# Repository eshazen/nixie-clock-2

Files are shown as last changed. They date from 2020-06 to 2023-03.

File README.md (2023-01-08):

# nixie-clock-2
Simple nixie clock based on ATMega861 microcontroller

<table>
  <tr>
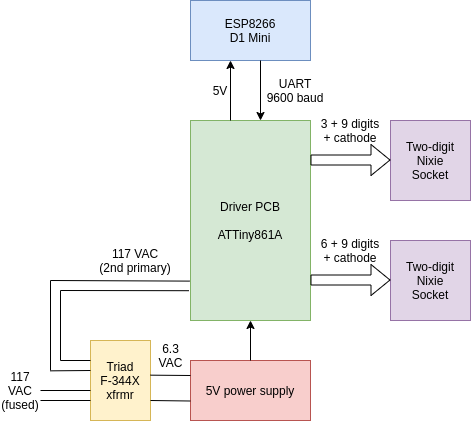
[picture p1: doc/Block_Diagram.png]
    <td width=50%>
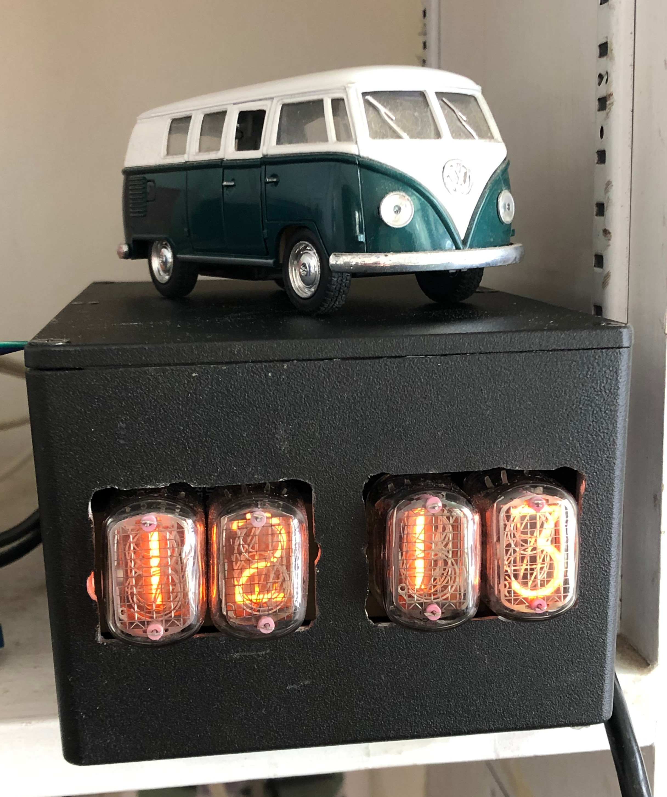
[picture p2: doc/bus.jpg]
    <td>
</table>

```hardware/DriverBoard```

ExpressPCB layout for MCU/Driver board with ATTiny861A driving 4 IN-2B nixies.

```hardware/nixie_socket```

KiCAD design for a two-digit nixie mounting/breakout board

```software/clock```

C code for ATTiny861A to drive the clock display

```software/ESP8266```

Very simple NTP client to get the time via WiFi and send to the ATTiny

## Plans

Thinking of building one for the Kitchen.  Instead of ESP8622, thinking
of one of many DS3231 I2C RTC modules.  This could use the header wires
now used for the ESP.

For power, Triad FD4-10 has a dual 115V primary and 10VCT secondary.
Use a full-wave rectifier or bridge plus 7805 for 5V and the second primary
to generate the HV.  Also need a fuse/holder.

## Notes

On power-up/reboot, the ESP module transmits a blast of serial stuff
at a high bit rate.  This crashes the AVR code.  There's a 30 sec
timer which runs before enabling serial, but apparently the power-up
reset of the ESP sometimes fails.  So for now a reliable
power-up procedure:

* Apply AC power
* Press the reset button on the ESP fairly promptly

Then after 30s timeout things should come up OK.  I'd try to fix
this but can't easily locate my programming adapter for the AVR.

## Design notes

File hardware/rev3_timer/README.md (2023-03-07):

# Rev 3 Timer

This is another try at the "Nixie kitchen timer" originally conceived
in about 2000.  The first rev PCB (ExpressPCB mini board) I used for a
clock in my office; the 2nd rev for another clock with a separate
display board (elsewhere in this repo).

Now planning a new, integrated board with 4 IN-12A/B Nixies, ATMega
328 (168, 88) and the following UI features:

* 4 digit nixie display for primary timer (00:00 to 59:59)
* Multiple simultaneous timers with distinctive sounds
* Water/splash proof case with waterproof buttons

Optional features

* RTC for time display
* Auxiliary LCD display 

## Status

**2023-03-07**

Combo PCB layout done which can be sheared in the middle into control
and display sections.  RTC and aux LCD not included.  Note that we
have a working RTC on the scope clock board so that could be added.

Looking at 3D builds.  See 3D directory.

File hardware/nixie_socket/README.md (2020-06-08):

This is a design for a simple nixie breakout board for two IN-2B or
B-5991 nixies.  I used DB-25 type female pins as individual sockets
for the nixies.

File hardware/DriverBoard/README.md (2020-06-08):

This directory has the ExpressPCB classic design files for a
four-digit nixie clock driver board.  Power is provided by two
inputs... 120V ac through an *isolation transformer* and 5V from any
convenient supply.  Nixies are driven by SN75461 transistor array
drivers.  Note the 90V zener on the common terminal... this protects
the driver chips in case no digits are illuminated.

The drivers are in turn controlled by a long shift register built of
74LS164 octal serial-to-parallel shift register ICs, driven by 4 GPIOs
on the uC.  

The circuitry consisting of C4, R2 etc was supposed to provide a 60Hz
interrupt to the MCU for timekeeping but it never worked right and I
decided to use NTP time loaded serially from an ESP8266.

J4 is an old-school Atmel 10 pin programming connector.  You'll
probably need to make an adapter (as I did) to program the board with
a modern 6-pin cable.

There's an ambient light sensor which may be used at some point to dim
the nixies at night.

Q1 is a MOSFET which is intended to drive an external alarm buzzer.

J2 has 3 GPIOs, of which I use only pin 3 as a serial input.

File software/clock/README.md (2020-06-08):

Software for Nixie Clock on ExpressPCB board with ATMega861A

Drives four IN-2B nixies attached via ribbon cables to two-digit
breakout boards.  The wiring is a bit crazy and you will probably have
to just work it out yourself.

9600 baud serial I/O working with some effort:

Timer interrupt at 9600Hz using divide-by-1
clock source (8MHz) divided by 800.
(calculated value 833)

Transmit using timer interrupt.

Receive using pin-change to start, set timer
to half-value to reset timer interrupts to occur
in the middle of the bit period.

Time is updated (only) by serial messages received at 9600 baud with
the format "*hhmm$".

Build using Makefile.  Expects avr-libc and avr-gcc, binutils and
avrdude to be installed.

"make flash" to program your board once you set the avrdude options.

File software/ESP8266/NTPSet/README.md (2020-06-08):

ESP8266 NTP client.  Connect to WiFi, obtain time from NTP server once
every 10s and send via 9600 baud UART to the clock as "*hhmm$"

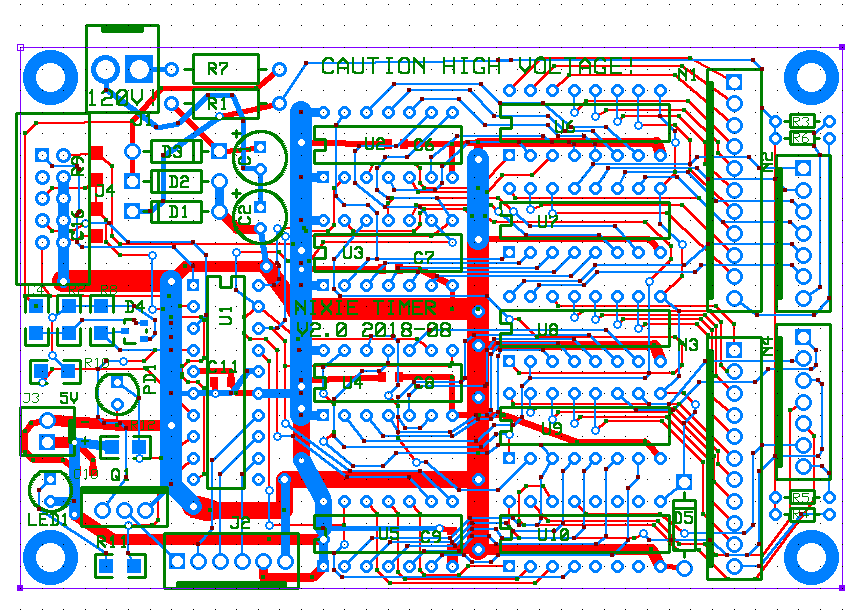
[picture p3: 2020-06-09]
hardware/DriverBoard/layout.png

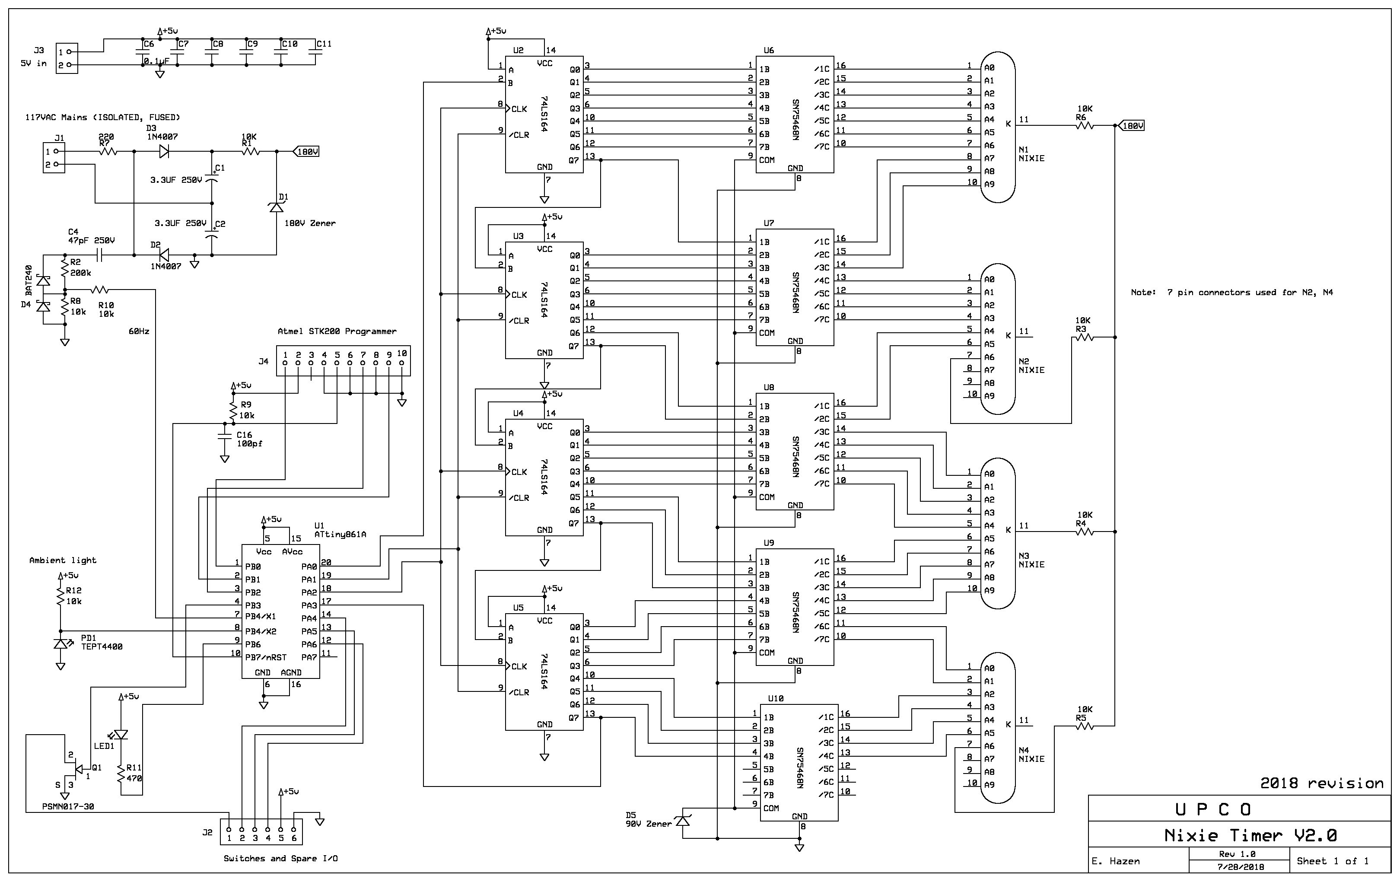
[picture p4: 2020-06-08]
hardware/DriverBoard/timer_sch.png

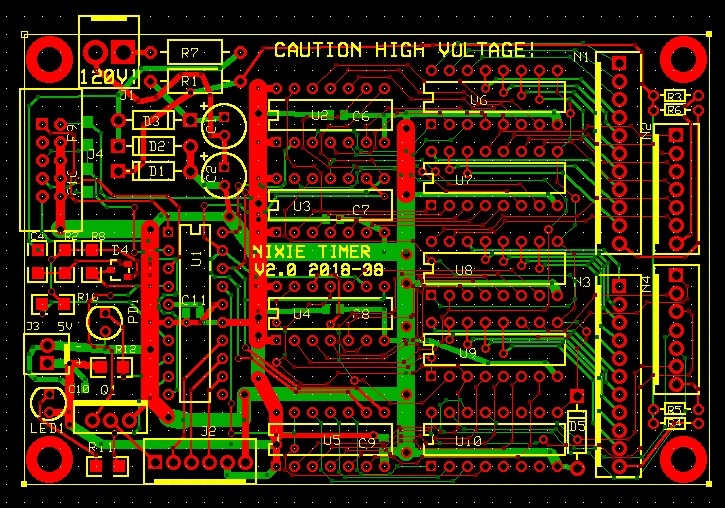
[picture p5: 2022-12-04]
pix/driver_layout.png

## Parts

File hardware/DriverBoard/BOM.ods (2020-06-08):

C1 | 3.3UF 250V | 1189-2223-ND
C2 | 3.3UF 250V | 1189-2223-ND
C4 | 47pF 250V | 311-3219-1-ND
C6 | 0.1uF | 311-1361-1-ND
C7 |  | 311-1361-1-ND
C8 |  | 311-1361-1-ND
C9 |  | 311-1361-1-ND
C10 |  | 311-1361-1-ND
C11 |  | 311-1361-1-ND
C16 | 100pf | 478-3999-1-ND
D1 | 180V Zener | C1Z180BCT-ND
D2 | 1N4007 | 1N4007-TPMSCT-ND
D3 | 1N4007 | 1N4007-TPMSCT-ND
D4 | BAT240 | BAT240AE6327HTSA1CT-ND
D5 | 90V Zener | 1N4763ACT-ND
J1 |  | WM4620
J2 | SIP 6 | S1211EC-06-ND
J3 |  | 732-5315-ND
J4 | Header 2x5 | MHB10K
LED1 |  | 754-1218-ND
N1 | NIXIE 11pin | S1211EC-11-ND
N2 | NIXIE 7pin | S1211EC-07-ND
N3 | NIXIE 11pin | S1211EC-11-ND
N4 | NIXIE 7pin | S1211EC-07-ND
PD1 | TEPT4400 | 751-1057-ND
Q1 | PSMN017-30 | 1727-7130-ND
R1 | 10K | PPC10KW-1CT-ND
R2 | 200k | RMCF1206FT200KCT-ND
R3 | 10K
R4 | 10K
R5 | 10K
R6 | 10K
R7 | 220 | PPC220W-1CT-ND
R8 | 10k | RMCF1206FT10K0CT-ND
R9 | 10k | RMCF1206FT10K0CT-ND
R10 | 10k | RMCF1206FT10K0CT-ND
R11 | 470 | RMCF1206FT470RCT-ND
R12 | 10k | RMCF1206FT10K0CT-ND
U1 | ATtiny861A | ATTINY861A-PU-ND
U2 | 74LS164 | 296-8248-5-ND
U3 | 74LS164 | 296-8248-5-ND
U4 | 74LS164 | 296-8248-5-ND
U5 | 74LS164 | 296-8248-5-ND
U6 | SN75468N | 296-9917-5-ND
U7 | SN75468N | 296-9917-5-ND
U8 | SN75468N | 296-9917-5-ND
U9 | SN75468N | 296-9917-5-ND
U10 | SN75468N | 296-9917-5-ND
U1-SKT | Qu: 1 | ED3020-ND
U2-5-SKT | Qu: 4 | ED3014-ND
U6-10-SKT | Qu: 5 | ED3016-ND
11 pin hsg | Qu: 2 | WM5342-ND
7 pin hsg | Qu: 2 | WM2805-ND
pin | Qu: 50 | WM2510CT-ND

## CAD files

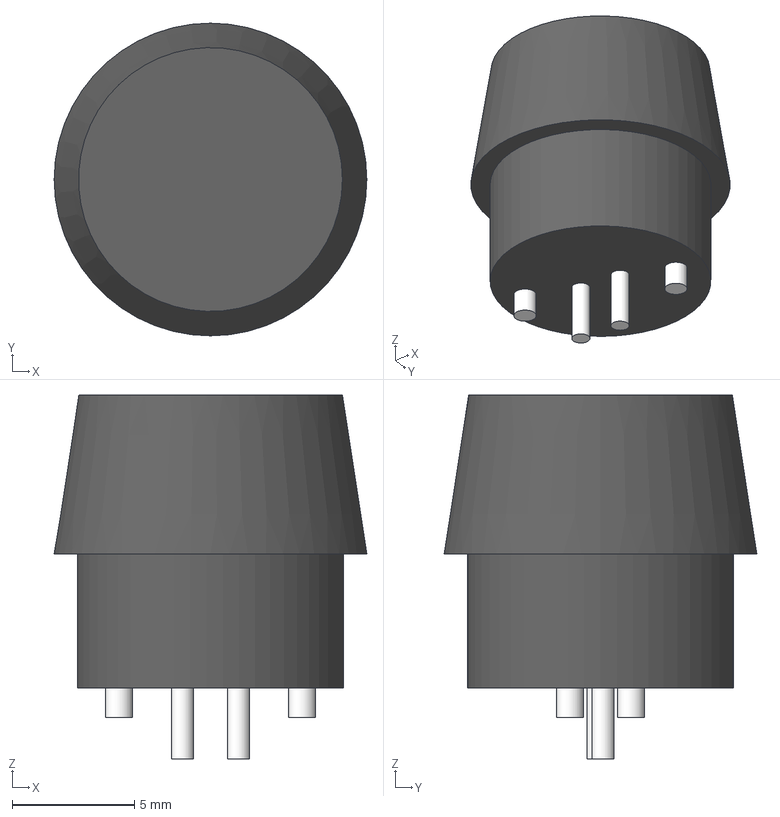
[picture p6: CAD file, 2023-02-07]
3D/rubber-button-Group.step
12.8 x 12.8 x 14.9 mm

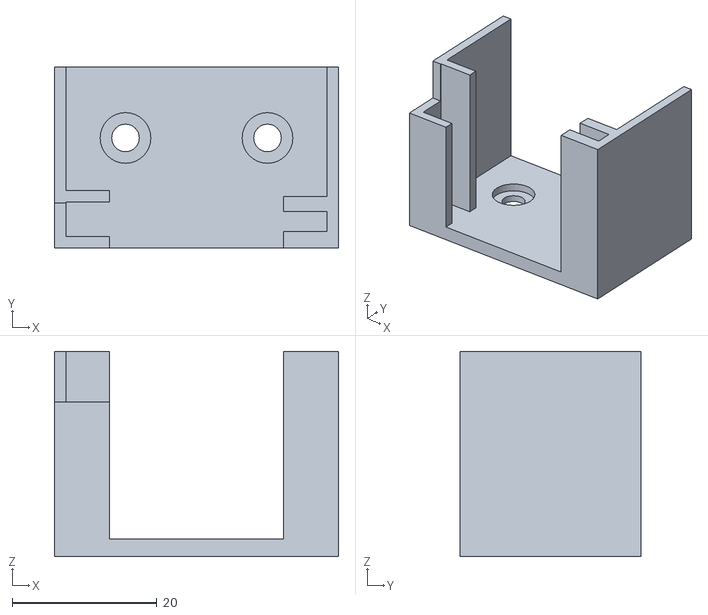
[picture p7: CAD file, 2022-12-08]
box/esp3_holder.stl
39.2 x 25.0 x 28.3

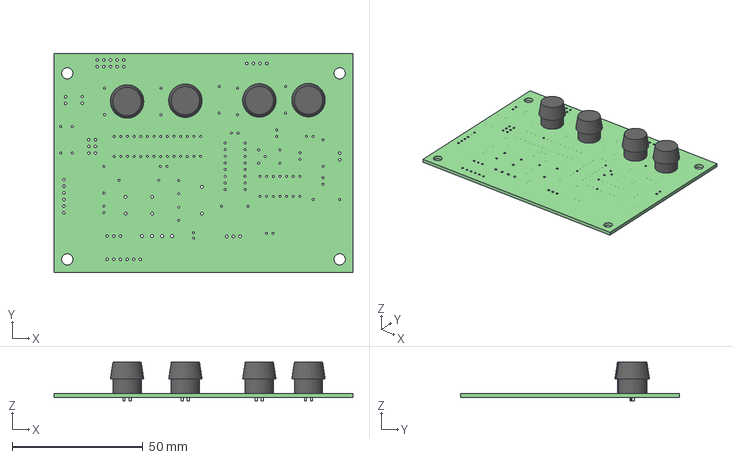
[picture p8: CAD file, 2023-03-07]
hardware/rev3_timer/3D/control.step
114.3 x 83.8 x 14.9 mm
control PCB

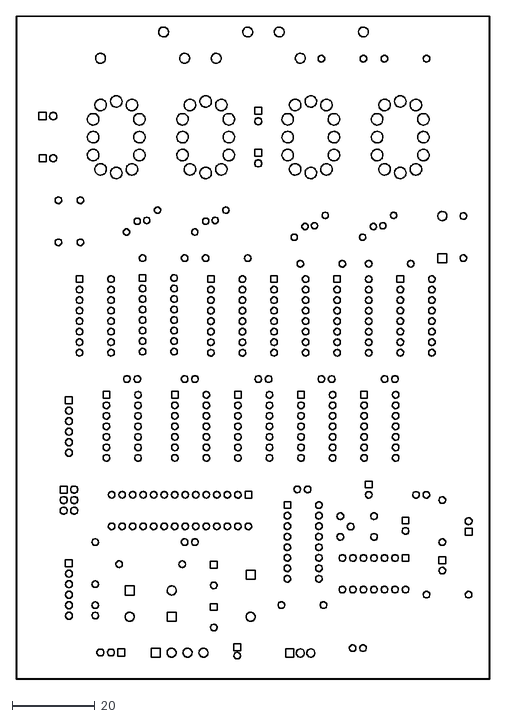
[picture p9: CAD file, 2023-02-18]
hardware/rev3_timer/dxf/rev3_timer-F_Cu.dxf
114.4 x 160.1

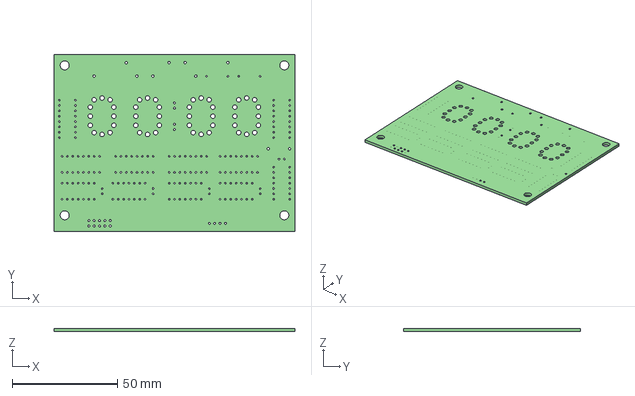
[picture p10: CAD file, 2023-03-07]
hardware/rev3_timer/3D/display.step
114.3 x 83.8 x 1.60 mm

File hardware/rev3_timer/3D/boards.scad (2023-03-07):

//
// test assembly for Nixie timer v3
// "control" and "display" boards hacked from combo board
// > exported as "VRML" from pcbnew
// > converted using imagetostl.com website
//

// two options, "flat" model with sloping control panel
// and "vertical" display model presented side-by-side

module display() {
     translate( [-34.5, 103, 0])
     scale( [1000, 1000, 1000]) import("display.stl");
}

module control() {
     translate( [-34.5, 103+83.4, 0])
     scale( [1000, 1000, 1000]) import("control.stl");
}


translate( [150, 0, 0]) {

// slant controls
color("orange") display();
translate( [0, -45, -5])
rotate([15, 0, 0])
color("green") control();
}

// vertical display
rotate( [90, 0, 0])
color("orange") display();
translate( [0, -70, -27])
rotate( [45, 0, 0])
color("green") control();

// base
translate( [0, -70, -30]) {
     cube( [114.3, 90, 1.6]);
     translate( [0, 90, 0])
     cube( [114.3, 1.6, 120]);
}

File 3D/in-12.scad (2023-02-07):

//
// IN-12 nixie
//

spd = 80;

module pin() {
     cylinder( d=1, h=6);
}

module nixie() {
     % intersection() {
	  cylinder( r=29/2, h=28);
	  translate( [-19.7/2, -30/2, 0])
	       cube( [19.7, 30, 28]);
	  translate( [0, 0, -(spd/2-27)])
	       sphere( d=spd);
     }
     translate( [0, 0, -6]) {
	  for( x=[0:1]) {
	       for( y=[0:2]) {
		    translate( [-11.5/2+x*11.5, -4.5+y*4.5, 0])
			 pin();
	       }
	  }
	  for( x=[0:1]) {
	       for( y=[0:1]) {
		    translate( [-8/2+x*8, -8+y*16, 0])
			 pin();
	       }
	  }
	  translate( [0, -9, 0]) pin();
	  translate( [0, 9, 0]) pin();
     }
}

nixie();

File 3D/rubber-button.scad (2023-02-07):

//
// CK K12C sealed rubber button
//

$fn=64;

module button() {
     color("black") {
	  translate( [0, 0, 5.5])
	       cylinder( r1=6.4, r2=5.4, h=6.5);
	  cylinder( h=5.5, r=10.9/2);
     }
     translate( [-7.5/2, -2.5/2, -1.2])     cylinder( r=1.1/2, h=1.2);
     translate( [7.5/2, 2.5/2, -1.2])    cylinder( r=1.1/2, h=1.2);
     translate( [-2.3/2, -0.1, -2.9])   cylinder( h=2.9, r=0.9/2);
     translate( [2.3/2, 0.1, -2.9])   cylinder( h=2.9, r=0.9/2);
}

button();

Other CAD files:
box/esp_holder.scad

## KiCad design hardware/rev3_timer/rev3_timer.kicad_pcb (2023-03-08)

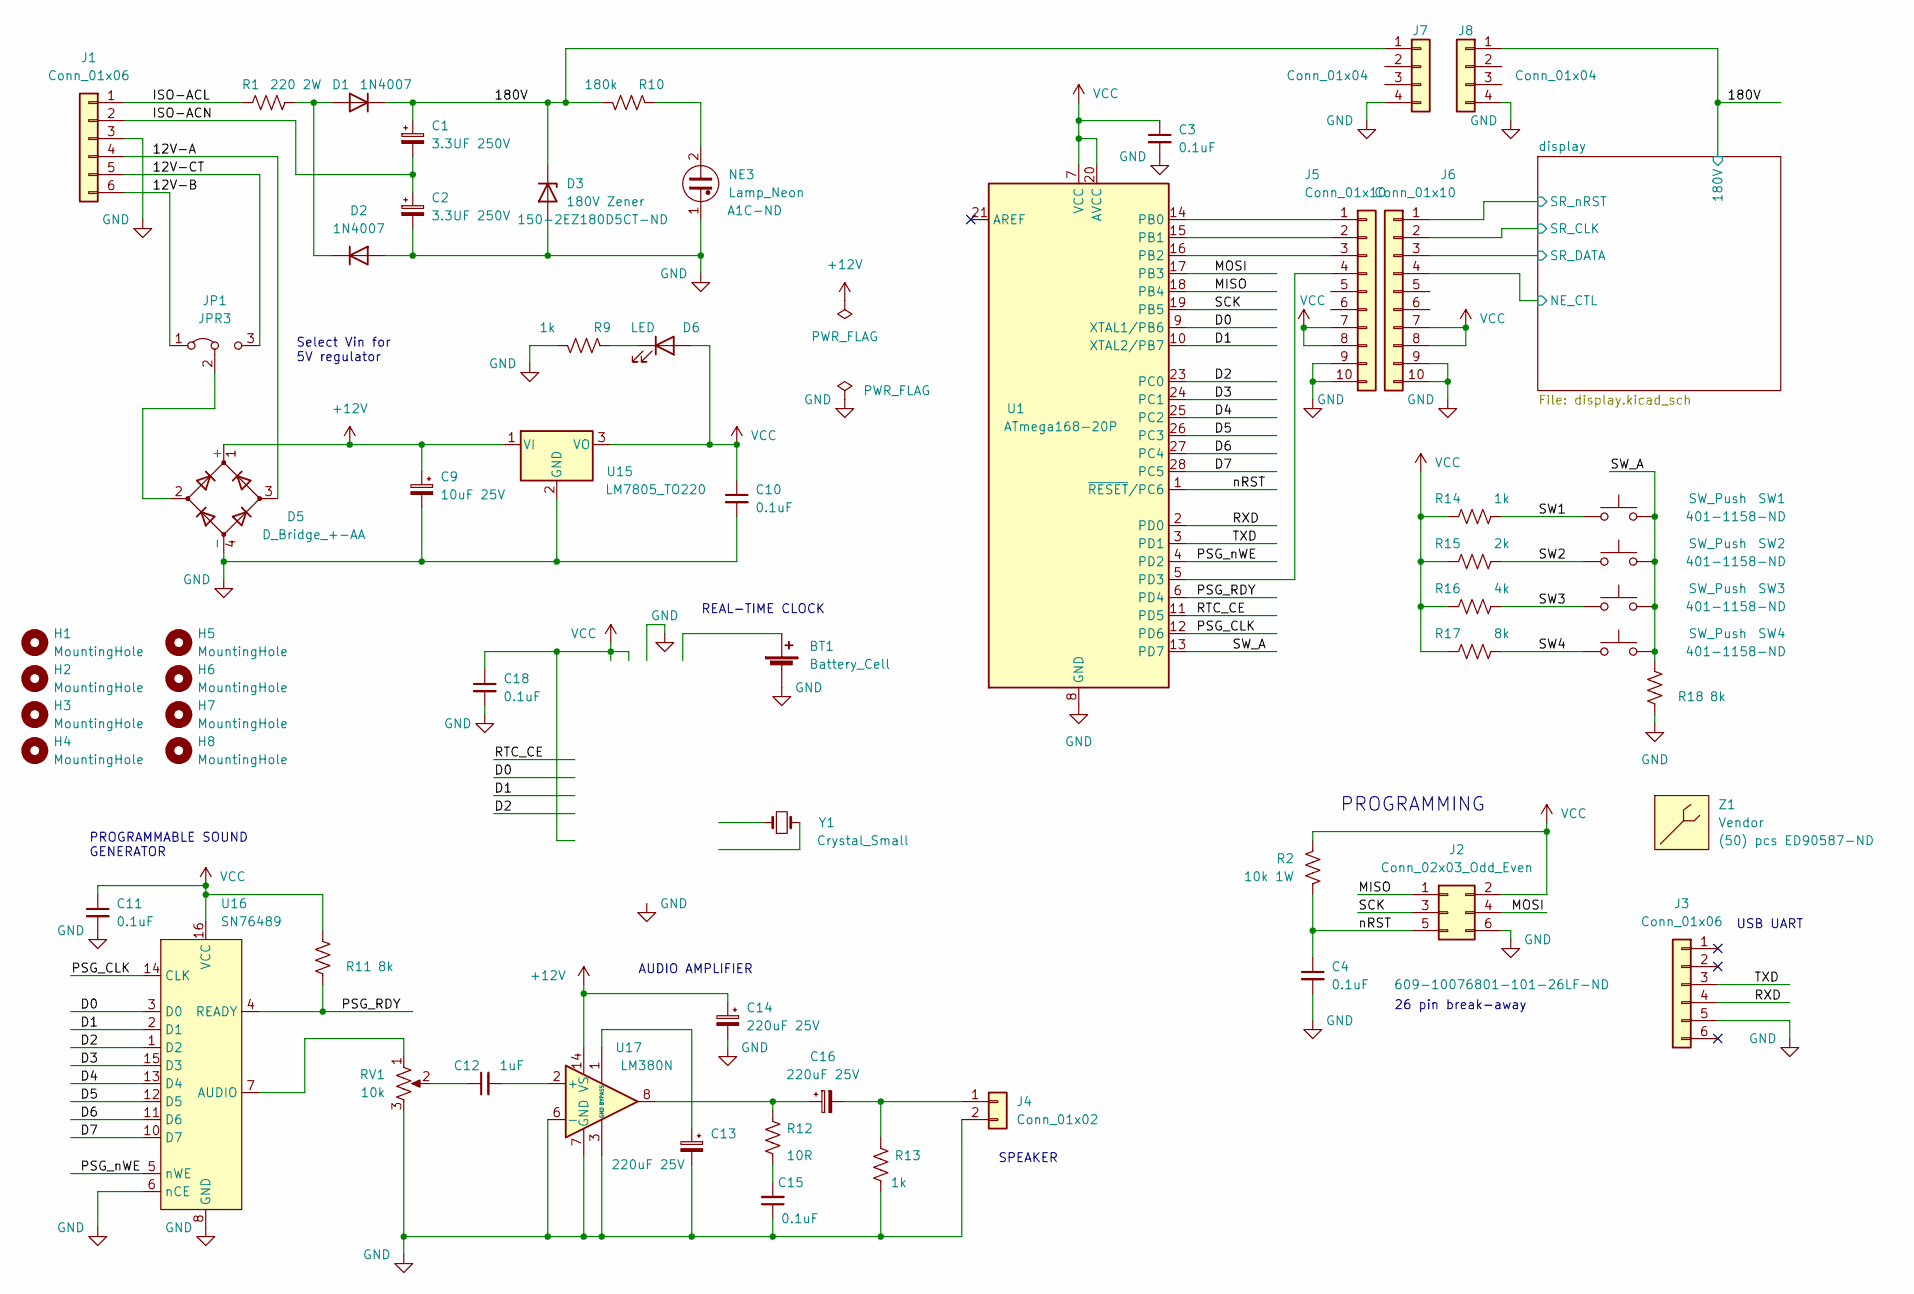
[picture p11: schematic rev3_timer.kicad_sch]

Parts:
BT1: Battery_Cell
C1, C2: 3.3UF 250V; CP_Radial_D8.0mm_P5.00mm
C3, C4, C10, C11, C15, C18: 0.1uF; C_Disc_D3.0mm_W1.6mm_P2.50mm
C9: 10uF 25V; CP_Radial_D5.0mm_P2.00mm
C12: 1uF; C_Rect_L7.2mm_W2.5mm_P5.00mm_FKS2_FKP2_MKS2_MKP2
C13, C14, C16: 220uF 25V; CP_Radial_D6.3mm_P2.50mm
D1, D2: 1N4007; D_DO-41_SOD81_P10.16mm_Horizontal
D3: 180V Zener; D_DO-41_SOD81_P10.16mm_Horizontal
D5: D_Bridge_+-AA; Diode_Bridge_Vishay_KBPM
D6: LED; LED_D3.0mm
H1, H2, H3, H4, H5, H6, H7, H8: MountingHole; MountingHole_4.3mm_M4_Pad
J1, J3: Conn_01x06; PinHeader_1x06_P2.54mm_Vertical
J2: Conn_02x03_Odd_Even; PinHeader_2x03_P2.54mm_Vertical
J4: Conn_01x02; PinHeader_1x02_P2.54mm_Vertical
J5, J6: Conn_01x10; PinHeader_2x05_P2.54mm_Vertical
J7, J8: Conn_01x04; PinHeader_1x04_P2.54mm_Vertical
JP1: JPR3; PinHeader_1x03_P2.54mm_Vertical
NE3: Lamp_Neon; PinHeader_1x02_P2.54mm_Vertical
R1: 220 2W; R_Axial_DIN0309_L9.0mm_D3.2mm_P15.24mm_Horizontal
R2: 10k 1W; R_Axial_DIN0207_L6.3mm_D2.5mm_P10.16mm_Horizontal
R9, R13, R14: 1k; R_Axial_DIN0207_L6.3mm_D2.5mm_P10.16mm_Horizontal
R10: 180k; R_Axial_DIN0207_L6.3mm_D2.5mm_P10.16mm_Horizontal
R11, R17, R18: 8k; R_Axial_DIN0207_L6.3mm_D2.5mm_P10.16mm_Horizontal
R12: 10R; R_Axial_DIN0207_L6.3mm_D2.5mm_P10.16mm_Horizontal
R15: 2k; R_Axial_DIN0207_L6.3mm_D2.5mm_P10.16mm_Horizontal
R16: 4k; R_Axial_DIN0207_L6.3mm_D2.5mm_P10.16mm_Horizontal
RV1: 10k; Potentiometer_ACP_CA6-H2,5_Horizontal
SW1, SW2, SW3, SW4: SW_Push; ck-switch-k12c
U1: ATmega168-20P; DIP-28_W7.62mm
U15: LM7805_TO220; TO-220-3_Vertical
U16: SN76489; DIP-16_W7.62mm_Socket
U17: LM380N; DIP-14_W7.62mm
Y1: Crystal_Small; Crystal_C26-LF_D2.1mm_L6.5mm_Horizontal
Z1: BOM_Item

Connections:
+12V: C9.1, C14.1, D5.1 (+), U15.1 (VI), U17.14 (VS)
/180V: C1.1, D1.1 (K), D3.1 (K), J7.1, J8.1, R10.1; also elsewhere on the board
/D0: U1.9 (XTAL1/PB6), U16.3 (D0); also elsewhere on the board
/D1: U1.10 (XTAL2/PB7), U16.2 (D1); also elsewhere on the board
/D2: U1.23 (PC0), U16.1 (D2); also elsewhere on the board
/D3: U1.24 (PC1), U16.15 (D3)
/D4: U1.25 (PC2), U16.13 (D4)
/D5: U1.26 (PC3), U16.12 (D5)
/D6: U1.27 (PC4), U16.11 (D6)
/D7: U1.28 (PC5), U16.10 (D7)
/ISO-ACL: J1.1, R1.1
/ISO-ACN: C1.2, C2.1, J1.2
/MISO: J2.1, U1.18 (PB4)
/MOSI: J2.4, U1.17 (PB3)
/PSG_CLK: U1.12 (PD6), U16.14 (CLK)
/PSG_RDY: R11.1, U1.6 (PD4), U16.4 (READY)
/PSG_nWE: U1.4 (PD2), U16.5 (nWE)
/RTC_CE: U1.11 (PD5); also elsewhere on the board
/RXD: J3.4, U1.2 (PD0)
/SCK: J2.3, U1.19 (PB5)
/SW1: R14.2, SW1.1
/SW2: R15.2, SW2.1
/SW3: R16.2, SW3.1
/SW4: R17.2, SW4.1
/SW_A: R18.2, SW1.2, SW2.2, SW3.2, SW4.2, U1.13 (PD7)
/TXD: J3.3, U1.3 (PD1)
/display/NE_CTL: J6.4; also elsewhere on the board
/display/SR_CLK: J6.2; also elsewhere on the board
/display/SR_DATA: J6.3; also elsewhere on the board
/display/SR_nRST: J6.1; also elsewhere on the board
/nRST: C4.1, J2.5, R2.1, U1.1 (~RESET/PC6)
unnamed: C12.1, RV1.2
unnamed: C12.2, U17.2 (+)
unnamed: C13.1, U17.1 (BYPASS)
unnamed: C15.2, R12.1
unnamed: C16.1, R12.2, U17.8
unnamed: C16.2, J4.1, R13.2
unnamed: D1.2 (A), D2.1 (K), R1.2
unnamed: D5.2, JP1.2 (C)
unnamed: D6.1 (K), R9.2
unnamed: J5.1, U1.14 (PB0)
unnamed: J5.2, U1.15 (PB1)
unnamed: J5.3, U1.16 (PB2)
unnamed: J5.4, U1.5 (PD3)
unnamed: NE3.2, R10.2
unnamed: RV1.1, U16.7 (AUDIO)
unnamed 135: Y1.1; also elsewhere on the board
unnamed 136: Y1.2; also elsewhere on the board
VCC: C3.1, C10.1, C11.1, C18.1, D6.2 (A), J2.2, J5.7, J5.8, J6.7, J6.8, R2.2, R11.2, R14.1, R15.1, R16.1, R17.1, U1.7 (VCC), U1.20 (AVCC), U15.3 (VO), U16.16 (VCC); also elsewhere on the board

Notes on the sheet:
AUDIO AMPLIFIER
USB UART
Select Vin for 5V regulator
26 pin break-away
PROGRAMMING
PROGRAMMABLE SOUND GENERATOR
REAL-TIME CLOCK
SPEAKER

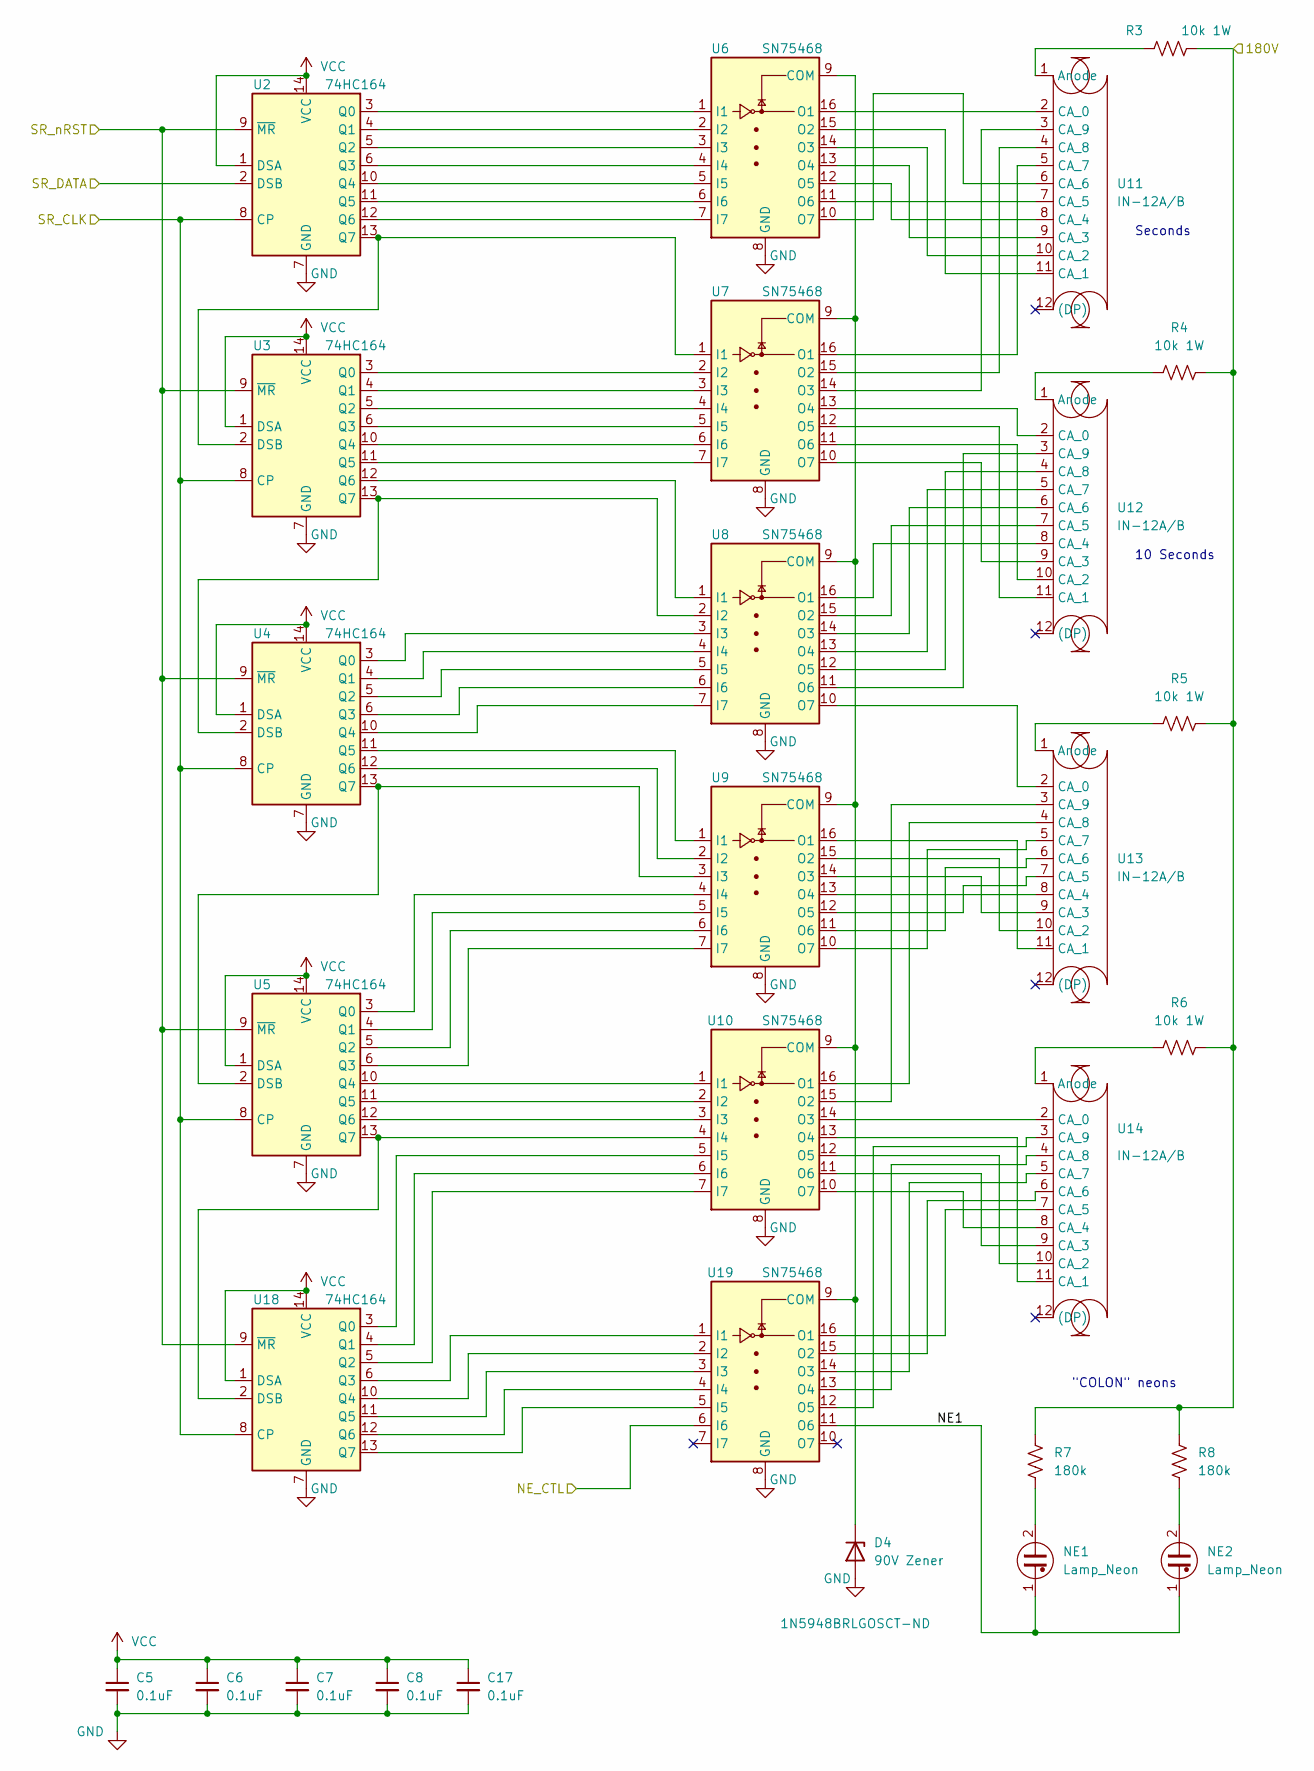
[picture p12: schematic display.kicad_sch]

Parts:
C5, C6, C7, C8, C17: 0.1uF; C_Disc_D3.0mm_W1.6mm_P2.50mm
D4: 90V Zener; D_DO-41_SOD81_P10.16mm_Horizontal
NE1, NE2: Lamp_Neon; PinHeader_1x02_P2.54mm_Vertical
R3, R4, R5, R6: 10k 1W; R_Axial_DIN0414_L11.9mm_D4.5mm_P20.32mm_Horizontal
R7, R8: 180k; R_Axial_DIN0207_L6.3mm_D2.5mm_P10.16mm_Horizontal
U2, U3, U4, U5, U18: 74HC164; DIP-14_W7.62mm_Socket
U6, U7, U8, U9, U10, U19: SN75468; DIP-16_W7.62mm_Socket
U11, U12, U13, U14: IN-12A/B; Nixie-8422-14pin

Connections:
/180V: R3.2, R4.2, R5.2, R6.2, R7.2, R8.2; also elsewhere on the board
/display/NE1: NE1.1, NE2.1, U19.11 (O6)
/display/NE_CTL: U19.6 (I6); also elsewhere on the board
/display/SR_CLK: U2.8 (CP), U3.8 (CP), U4.8 (CP), U5.8 (CP), U18.8 (CP); also elsewhere on the board
/display/SR_DATA: U2.2 (DSB); also elsewhere on the board
/display/SR_nRST: U2.9 (~MR), U3.9 (~MR), U4.9 (~MR), U5.9 (~MR), U18.9 (~MR); also elsewhere on the board
unnamed: D4.1 (K), U6.9 (COM), U7.9 (COM), U8.9 (COM), U9.9 (COM), U10.9 (COM), U19.9 (COM)
unnamed: NE1.2, R7.1
unnamed: NE2.2, R8.1
unnamed: R3.1, U11.1 (Anode)
unnamed: R4.1, U12.1 (Anode)
unnamed: R5.1, U13.1 (Anode)
unnamed: R6.1, U14.1 (Anode)
unnamed: U2.3 (Q0), U6.1 (I1)
unnamed: U2.4 (Q1), U6.2 (I2)
unnamed: U2.5 (Q2), U6.3 (I3)
unnamed: U2.6 (Q3), U6.4 (I4)
unnamed: U2.10 (Q4), U6.5 (I5)
unnamed: U2.11 (Q5), U6.6 (I6)
unnamed: U2.12 (Q6), U6.7 (I7)
unnamed: U2.13 (Q7), U3.2 (DSB), U7.1 (I1)
unnamed: U3.3 (Q0), U7.2 (I2)
unnamed: U3.4 (Q1), U7.3 (I3)
unnamed: U3.5 (Q2), U7.4 (I4)
unnamed: U3.6 (Q3), U7.5 (I5)
unnamed: U3.10 (Q4), U7.6 (I6)
unnamed: U3.11 (Q5), U7.7 (I7)
unnamed: U3.12 (Q6), U8.1 (I1)
unnamed: U3.13 (Q7), U4.2 (DSB), U8.2 (I2)
unnamed: U4.3 (Q0), U8.3 (I3)
unnamed: U4.4 (Q1), U8.4 (I4)
unnamed: U4.5 (Q2), U8.5 (I5)
unnamed: U4.6 (Q3), U8.6 (I6)
unnamed: U4.10 (Q4), U8.7 (I7)
unnamed: U4.11 (Q5), U9.1 (I1)
unnamed: U4.12 (Q6), U9.2 (I2)
unnamed: U4.13 (Q7), U5.2 (DSB), U9.3 (I3)
unnamed: U5.3 (Q0), U9.4 (I4)
unnamed: U5.4 (Q1), U9.5 (I5)
unnamed: U5.5 (Q2), U9.6 (I6)
unnamed: U5.6 (Q3), U9.7 (I7)
unnamed: U5.10 (Q4), U10.1 (I1)
unnamed: U5.11 (Q5), U10.2 (I2)
unnamed: U5.12 (Q6), U10.3 (I3)
unnamed: U5.13 (Q7), U10.4 (I4), U18.2 (DSB)
unnamed: U10.5 (I5), U18.3 (Q0)
unnamed: U10.6 (I6), U18.4 (Q1)
unnamed: U10.7 (I7), U18.5 (Q2)
unnamed: U10.10 (O7), U14.8 (CA_4)
unnamed: U10.11 (O6), U14.9 (CA_3)
unnamed: U10.12 (O5), U14.10 (CA_2)
unnamed: U10.13 (O4), U14.11 (CA_1)
unnamed: U10.14 (O3), U14.2 (CA_0)
unnamed: U10.15 (O2), U13.3 (CA_9)
unnamed: U10.16 (O1), U13.4 (CA_8)
unnamed: U6.16 (O1), U11.2 (CA_0)
unnamed: U7.14 (O3), U11.3 (CA_9)
unnamed: U7.15 (O2), U11.4 (CA_8)
unnamed: U7.16 (O1), U11.5 (CA_7)
unnamed: U6.10 (O7), U11.6 (CA_6)
unnamed: U6.11 (O6), U11.7 (CA_5)
unnamed: U6.12 (O5), U11.8 (CA_4)
unnamed: U6.13 (O4), U11.9 (CA_3)
unnamed: U6.14 (O3), U11.10 (CA_2)
unnamed: U6.15 (O2), U11.11 (CA_1)
unnamed: U7.13 (O4), U12.2 (CA_0)
unnamed: U8.11 (O6), U12.3 (CA_9)
unnamed: U8.12 (O5), U12.4 (CA_8)
unnamed: U8.13 (O4), U12.5 (CA_7)
unnamed: U8.14 (O3), U12.6 (CA_6)
unnamed: U8.15 (O2), U12.7 (CA_5)
unnamed: U8.16 (O1), U12.8 (CA_4)
unnamed: U7.10 (O7), U12.9 (CA_3)
unnamed: U7.11 (O6), U12.10 (CA_2)
unnamed: U7.12 (O5), U12.11 (CA_1)
unnamed: U8.10 (O7), U13.2 (CA_0)
unnamed: U9.10 (O7), U13.5 (CA_7)
unnamed: U9.11 (O6), U13.6 (CA_6)
unnamed: U9.12 (O5), U13.7 (CA_5)
unnamed: U9.13 (O4), U13.8 (CA_4)
unnamed: U9.14 (O3), U13.9 (CA_3)
unnamed: U9.15 (O2), U13.10 (CA_2)
unnamed: U9.16 (O1), U13.11 (CA_1)
unnamed: U14.3 (CA_9), U19.12 (O5)
unnamed: U14.4 (CA_8), U19.13 (O4)
unnamed: U14.5 (CA_7), U19.14 (O3)
unnamed: U14.6 (CA_6), U19.15 (O2)
unnamed: U14.7 (CA_5), U19.16 (O1)
unnamed: U18.6 (Q3), U19.1 (I1)
unnamed: U18.10 (Q4), U19.2 (I2)
unnamed: U18.11 (Q5), U19.3 (I3)
unnamed: U18.12 (Q6), U19.4 (I4)
unnamed: U18.13 (Q7), U19.5 (I5)
VCC: C5.1, C6.1, C7.1, C8.1, C17.1, U2.1 (DSA), U2.14 (VCC), U3.1 (DSA), U3.14 (VCC), U4.1 (DSA), U4.14 (VCC), U5.1 (DSA), U5.14 (VCC), U18.1 (DSA), U18.14 (VCC); also elsewhere on the board

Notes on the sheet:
"COLON" neons
Seconds
10 Seconds

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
Board: 2 copper layers, 88 parts (0 on the bottom side), 141 nets, no tracks yet.

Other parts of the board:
U20: DS1306; DIP-16_W7.62mm_Socket

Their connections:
/D0: U20.11 (SCLK); also elsewhere on the board
/D1: U20.12 (SDI); also elsewhere on the board
/D2: U20.13 (SDO); also elsewhere on the board
/RTC_CE: U20.10 (CE); also elsewhere on the board
unnamed 135: U20.3 (X1); also elsewhere on the board
unnamed 136: U20.4 (X2); also elsewhere on the board
VCC: U20.9 (SERMODE), U20.14 (VCCIF), U20.16 (VCC); also elsewhere on the board

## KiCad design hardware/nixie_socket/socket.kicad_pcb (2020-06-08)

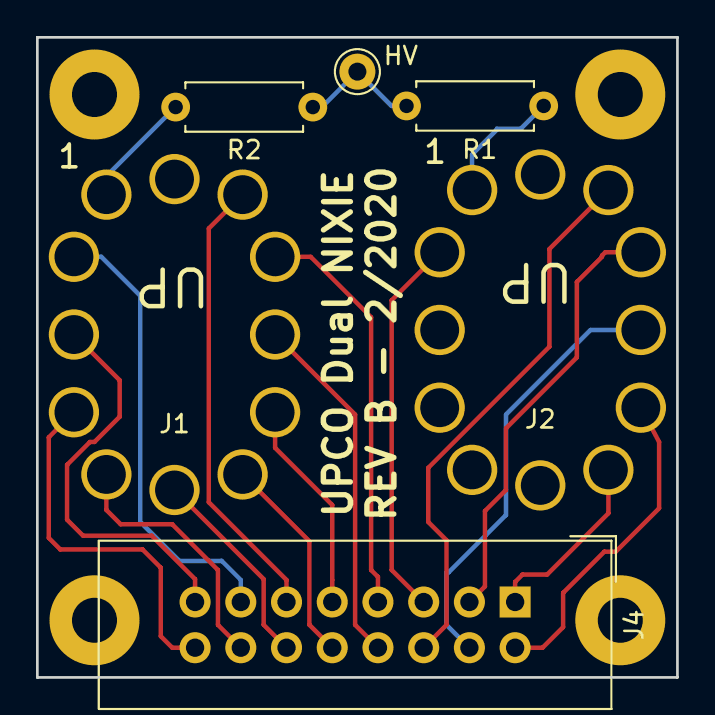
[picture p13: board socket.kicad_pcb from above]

Board: 2 copper layers, 35.6 x 35.6 mm, 7 parts (0 on the bottom side), 19 nets.

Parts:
J1, J2: Nixie; Nixie-8422-14pin
J3: HV; Pin_D1.0mm_L10.0mm
J4: Conn_02x08_Odd_Even; IDC-Header_2x08_P2.54mm_Vertical
R1, R2: R_US; R_Axial_DIN0207_L6.3mm_D2.5mm_P7.62mm_Horizontal
x1: MountingHole_2.5mm_Pad

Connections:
unnamed: J1.1, R2.2
unnamed: J1.2, J4.13
unnamed: J1.3, J4.15
unnamed: J1.4, J4.16
unnamed: J1.5, J4.14
unnamed: J1.6, J4.12
unnamed: J1.7, J4.10
unnamed: J1.8, J4.9
unnamed: J1.9, J4.8
unnamed: J1.10, J4.7
unnamed: J1.11, J4.11
unnamed: J2.1, R1.2
unnamed: J2.2, J4.5
unnamed: J2.7, J4.1
unnamed: J2.8, J4.2
unnamed: J2.9, J4.4
unnamed: J2.10, J4.3
unnamed: J2.11, J4.6
unnamed: J3.1, R1.1, R2.1

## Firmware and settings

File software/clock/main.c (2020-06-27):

// Nixie Clock II
//
// 1Hz timer interrupts
// pin-change interrupt on PA5 starts timer-driven UART
// set time via UART at 9600 baud   "*hhmm$"
//
// boot-up rubbish out of ESP8266 seems to crash our cheezy UART,
// so delay 30s at power-up before enabling
//
// 

#include <avr/io.h>
#include <util/delay.h>
#include <avr/interrupt.h>
#include <ctype.h>

volatile uint8_t sec, min, min10, hr, hr10;

// counts at TIMER_HZ rate
volatile uint16_t tick1k;	/* 9600Hz counter */
volatile uint8_t tick1s;	/* startup 1Hz counter */
volatile uint8_t ready;

#include "timeofday.h"
#include "clock.h"
#include "display.h"
#include "uart.h"

void ioinit();

// pin change interrupt
ISR( PCINT_vect)
{
  // disable further pin change interrupts
  GIMSK &= ~_BV(PCIE1);  
  // set timer to half way through bit period
  TCNT0H = CNT_HALF_HI;
  TCNT0L = CNT_HALF_LOW;
  uart_rx_start();
}

// interrupt at 9600Hz
ISR( TIMER0_OVF_vect)		// timer1 ISR
{
  TCNT0H = CNT_HI;
  TCNT0L = CNT_LOW;
  uart_tick();
  ++tick1k;
}

uint8_t send = 32;

// receive buffer for time messages
#define TIME_LEN 10
static char buff[TIME_LEN];
static char *p;

int main (void)
{
  ioinit();
  sei();
  uint16_t i;
  
  while( 1) {
    
#ifdef UART_SET
    if( ready && (send = uart_getc())) {
      if( send == '*') {
	p = buff;
      } else if( send == '$') {
	if( (p-buff) == 4) {
	  hr10  = buff[0] - '0';
	  hr    = buff[1] - '0';
	  min10 = buff[2] - '0';
	  min   = buff[3] - '0';
	}
      } else if( isdigit( send) && (p-buff) < TIME_LEN) {
	*p++ = send;
      }
    }
#endif

    if( tick1k >= 9600) {
      tick1k = 0;
      PORTB ^= nLED;		/* toggle LED */

      // increment tick1s until 1 minute has passed, then
      // initialize UART
      if( !ready) {
	++tick1s;
	if( tick1s == 30) {	/* power up delay 1 minute */
	  ready = 1;
	  GIMSK = _BV(PCIE1);		/* enable UART pin change interrupt */
	}
	// display count-down time
	min10 = tick1s / 10;
	min = tick1s % 10;
      }

#ifdef TESTDPY
      inc_min();
      inc_hr();
#endif
#ifdef INTERNAL_TIME
      inc_time();
#endif
      set_digits( hr10, hr, min10, min);
    }
  }
}

void ioinit() {
  DDRB = _BV(3) | _BV(6);       /* PB3, PB6 output */
  DDRA = 7;			/* set 3 LSBs as output */

  PORTB = 0;

  DDRA |= _BV(4);		/* only PA4 is output */

  PORTB |= nLED;		/* turn off LED */

  PORTA = 0;			/* all low including nCLR */
  /* deassert CLR, activate pull-ups on buttons */
  PORTA |= SR_CLR | SET_MIN | SET_HR;
  
  TCNT0H = CNT_HI;
  TCNT0L = CNT_LOW;

  TCCR0A = 0x80;		/* set only TCW0 for 16 bits */
  TCCR0B = CNT_PS_CODE;		/* set clock prescale */
  TIMSK = (1 << TOIE0);		/* enable timer interrupt */

  /* reset system clock divider to 1 so 8MHz clock */
  CLKPR = _BV(CLKPCE);
  CLKPR = 0;

  /* enable interrupt on PA5 (PCINT5) */
  uart_init();
  //  don't enable PC interrupt until ready
  //  PCMSK0 = _BV(PCINT5);
  PCMSK1 = 0;

  /* try fiddling with oscillator calibration */
  /* this seems about right */
  OSCCAL = 0x8d;

  ready = 0;
  // enable UART (pin change) interrupt mask
  PCMSK0 = _BV(PCINT5);
}

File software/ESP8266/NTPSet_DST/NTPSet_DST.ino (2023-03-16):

/*
 * Connect to NTP time server via WiFi
 * Once every 10s send out a message via serial to UART0 at 9600 baud
 * "*hhmm$"
 * 
 * Attempt to correct for DST in US Eastern zone
 */

#include <NTPClient.h>
#include <ESP8266WiFi.h>
#include <WiFiUdp.h>
#include <TimeLib.h>
#include <time.h>
#include <Timezone.h>

const char *ssid     = "wiggle24";
const char *password = "123456789b";

// we're at UTC-4 currently
const long utcOffsetInSeconds = (-4*3600);

TimeChangeRule usEDT = {"EDT", Second, Sun, Mar, 2, -240};  //UTC - 4 hours
TimeChangeRule usEST = {"EST", First, Sun, Nov, 2, -300};   //UTC - 5 hours
Timezone usEastern(usEDT, usEST);

// Define NTP Client to get time
WiFiUDP ntpUDP;
// NTPClient timeClient(ntpUDP, "pool.ntp.org", utcOffsetInSeconds);
NTPClient timeClient(ntpUDP, "pool.ntp.org", 0L);

void setup(){
  Serial.begin(9600);
  
  WiFi.begin(ssid, password);

  while ( WiFi.status() != WL_CONNECTED ) {
    delay ( 500 );
  }

  timeClient.begin();
}

static int hh, mm;

void loop() {
  timeClient.update();
  time_t localTime = usEastern.toLocal( timeClient.getEpochTime());
  
  struct tm *ptm = gmtime((time_t *)&localTime);

  hh = ptm->tm_hour;
  mm = ptm->tm_min;

  Serial.print("*");
  Serial.print( hh/10);
  Serial.print( hh%10);
  Serial.print( mm/10);
  Serial.print( mm%10);
  Serial.println("$");
  
    delay(10000);
}

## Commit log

2020-06-08 Uploading hardware design
    [BOM.csv, BOM.ods, timer.sch]
2020-06-08 Add socket PCB
    [BOM.csv, BOM.ods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]
2020-06-27 Clock firmware updates: disable on-board time update as it was fighting with the NTP time updates. Found that EPS8266 boot-up emits a high-baud blurp which would crash the AVR, so added a 30s start-u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
    [timer.sch]
2022-12-04 add ESP holder draft
    [esp_holder.scad]
2022-12-08 Holder seems to fit now
    [esp3_holder.stl, esp_holder.scad]
2023-02-06 socket board and new timer
    [display.kicad_sch, rev3_timer.kicad_pcb, rev3_timer.kicad_sch]
2023-02-06 .gitignore is now working
    [BOM.csv]
2023-02-07 working on placement
    [display.kicad_sch, in-12.scad, rev3_timer.kicad_pcb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]
2023-02-18 working on two-board design
    [rev3_timer-F_Cu.dxf, rev3_timer.kicad_pcb, rev3_timer.kicad_sch]
2023-03-06 playing with placement
    [rev3_timer.kicad_pcb, rev3_timer.kicad_sch]
2023-03-07 working on 3D
    [boards.scad, both.kicad_pcb, control.kicad_pcb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]
2023-03-08 add RTC, rearrange placement
    [rev3_timer.kicad_pcb, rev3_timer.kicad_sch]
